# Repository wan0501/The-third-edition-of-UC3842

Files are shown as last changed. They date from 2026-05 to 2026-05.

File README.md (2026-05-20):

# UC3842 第三版 — 85VAC~265VAC 输入 / 24VDC 3A 输出反激开关电源
本项目是一个基于 **UC3842**  PWM 控制芯片的**反激（Flyback）式开关电源**完整设计，提供 **85 VAC ~ 265 VAC 宽范围交流输入**、**24 VDC / 3 A（72 W）稳压直流输出**。
这是该电源的**第三版**设计，在之前版本基础上对电路参数、变压器设计和布局进行了全面优化。

---

## 目录

- [项目概述](#项目概述)
- [技术规格](#技术规格)
- [文件说明](#文件说明)
- [电路架构](#电路架构)
- [关键设计要点](#关键设计要点)
- [设计工具](#设计工具)
- [使用说明](#使用说明)
- [版本历史](#版本历史)
- [许可证](#许可证)

---

## 项目概述

本项目以 UC3842 电流模式 PWM 控制器为核心，设计一款适用于工业控制、仪器仪表、辅助供电等场景的隔离型反激开关电源。第三版重点对以下方面进行了改进：

- **优化变压器**：重新计算电感量、匝比和磁芯选择，提高效率
- **改进 EMI 滤波**：增强输入滤波和共模抑制
- **完善保护功能**：过流保护（OCP）、过压保护（OVP）、欠压锁定（UVLO）
- **优化布局**：减少噪声耦合，改善热管理

### 应用场景

- 工业控制系统辅助电源
- 仪器仪表供电
- 白色家电控制板电源
- 通用 AC-DC 适配器 / 基板电源

---

## 技术规格

| 参数 | 最小值 | 典型值 | 最大值 | 单位 |
|---|---|---|---|---|
| **输入电压 (AC)** | 85 | 220 | 265 | VAC |
| **输入频率** | 47 | 50/60 | 63 | Hz |
| **输出电压** | — | 24.0 | — | VDC |
| **输出电流** | 0 | 3.0 | — | A |
| **输出功率** | — | 72 | — | W |
| **开关频率** | — | ~65 | — | kHz |
| **效率** | >80 | ~85 | — | % |
| **纹波噪声** | — | <100 | — | mVpp |
| **负载调整率** | — | ±1 | — | % |
| **电压调整率** | — | ±0.5 | — | % |
| **隔离耐压** | 3000 | — | — | VAC |

---

## 文件说明

| 文件 | 说明 |
|---|---|
| `UC3842第三版.SchDoc` | **Altium Designer 原理图源文件**，包含完整的电路设计和元件参数 |
| `UC3842第三版.pdf` | **原理图 PDF 导出文件**，方便直接查看和打印 |
| `85AC~265VAC-DC24V3A.xlsx` | **变压器设计计算表格**，包含电感量、匝数、磁芯选型、损耗等详细计算 |
| `22LC串联谐振频率计算工具.xlsx` | **LC 串联谐振频率计算工具**，用于辅助设计 RCD 吸收回路 / 谐振网络 |

---

## 电路架构

### 系统框图

```
AC输入 (85~265V) → EMI滤波 → 桥式整流 → 输入滤波电容 → 反激变压器 → 输出整流滤波 → 24VDC 输出
                           ↑                        ↓
                       PWM 驱动 (UC3842) ←─── 反馈环路 (TL431 + 光耦)
```

### 主要功能模块

#### 1. 输入级
- **保险丝**：输入过流保护
- **NTC 热敏电阻**：抑制启动浪涌电流
- **共模扼流圈 + X 电容**：EMI 共模滤波
- **桥式整流器**：全波整流
- **大容量电解电容**：整流滤波，提供平滑直流母线

#### 2. 控制级 — UC3842
- **启动电阻**：上电启动，启动后由辅助绕组供电
- **RC 振荡**：设定开关频率（约 65 kHz）
- **电流检测电阻**：逐周期峰值电流限制
- **软启动**：缓启动电路，避免启动过冲

#### 3. 功率级 — 反激变换
- **MOSFET 开关管**：高压功率管
- **RCD 吸收回路**：抑制漏感尖峰电压
- **反激变压器**：储能、隔离、电压变换

#### 4. 输出级
- **肖特基整流二极管**：高效输出整流
- **LC 滤波**：降低输出纹波
- **假负载电阻**：保障空载稳定性

#### 5. 反馈环路
- **TL431 精密基准**：输出采样与误差放大
- **PC817 光耦**：隔离反馈，提供初级侧 PWM 控制

---

## 关键设计要点

### 变压器设计

变压器是反激电源的核心。计算表格 `85AC~265VAC-DC24V3A.xlsx` 中包含了详细的设计过程：

- **磁芯选型**：根据功率等级选择合适磁芯（如 EE / PQ / RM 系列）
- **匝比计算**：根据输入电压范围和输出电压确定最优匝比
- **电感量**：在 CCM / DCM 模式下优化电感量，平衡峰值电流和磁芯损耗
- **气隙计算**：防止磁饱和
- **绕组结构**：优化初级、次级、辅助绕组的排布，降低漏感
- **铜损 / 铁损**：校核温升

> **注意**：变压器参数已根据第三版优化调整，请勿直接套用前两版参数。

### RCD 吸收回路

- **LC 串联谐振频率计算工具**（`22LC串联谐振频率计算工具.xlsx`）辅助选择吸收电容和电阻
- 目标：将漏感尖峰电压控制在 MOSFET 耐压范围内（通常降额 80%~85%）
- 平衡：吸收效果 vs 损耗

### 反馈补偿

- Type II 补偿网络（TL431 + RC 网络）
- 穿越频率设为开关频率的 1/5 ~ 1/10
- 保证足够的相位裕度（>45°）

### 布局要点（建议）

- **功率回路**：最小化高频电流环路面积
- **控制地 / 功率地**：单点接地 / 星形接地
- **隔离间距**：初级 - 次级间确保安全爬电距离
- **散热**：MOSFET 和整流二极管留足铜皮散热

---

## 设计工具

| 工具 | 用途 |
|---|---|
| Excel 计算表格 | 变压器参数计算、LC 谐振频率计算 |
| UC3842 Datasheet (TI / OnSemi / ST) | 芯片参考设计 |

---

## 使用说明

### 查看原理图

1. **方式一（推荐）**：使用 Altium Designer 打开 `UC3842第三版.SchDoc`
2. **方式二**：直接打开 `UC3842第三版.pdf` 查看原理图 PDF

### 使用设计计算表格

- `85AC~265VAC-DC24V3A.xlsx`：修改黄色的输入参数单元格，自动计算变压器参数
- `22LC串联谐振频率计算工具.xlsx`：输入电感和电容值，自动计算谐振频率

### 注意事项

- **高压危险！** 调试时建议使用隔离变压器
- 初次上电建议串联调压器 + 灯泡限流
- 修改变压器参数后请重新验证磁通摆幅（ΔB），防止磁饱和

---

## 版本历史

| 版本 | 日期 | 说明 |
|---|---|---|
| V1.0 | — | 初始设计 |
| V2.0 | — | 优化反馈环路和 EMI |
| **V3.0** | **当前** | **全面优化变压器、吸收回路和布局** |

---

## 许可证

本项目基于 MIT 许可证开源 — 详见 [LICENSE](LICENSE) 文件。

---

## 免责声明

本项目为开源硬件设计参考，**不构成产品级设计保证**。使用者应自行验证电路参数是否满足自身应用需求。因使用本设计造成的任何损失，作者不承担责任。

---

**作者**: [wan0501](https://github.com/wan0501)

**如果这个项目对你有帮助，欢迎 Star ⭐ 和 Fork！**

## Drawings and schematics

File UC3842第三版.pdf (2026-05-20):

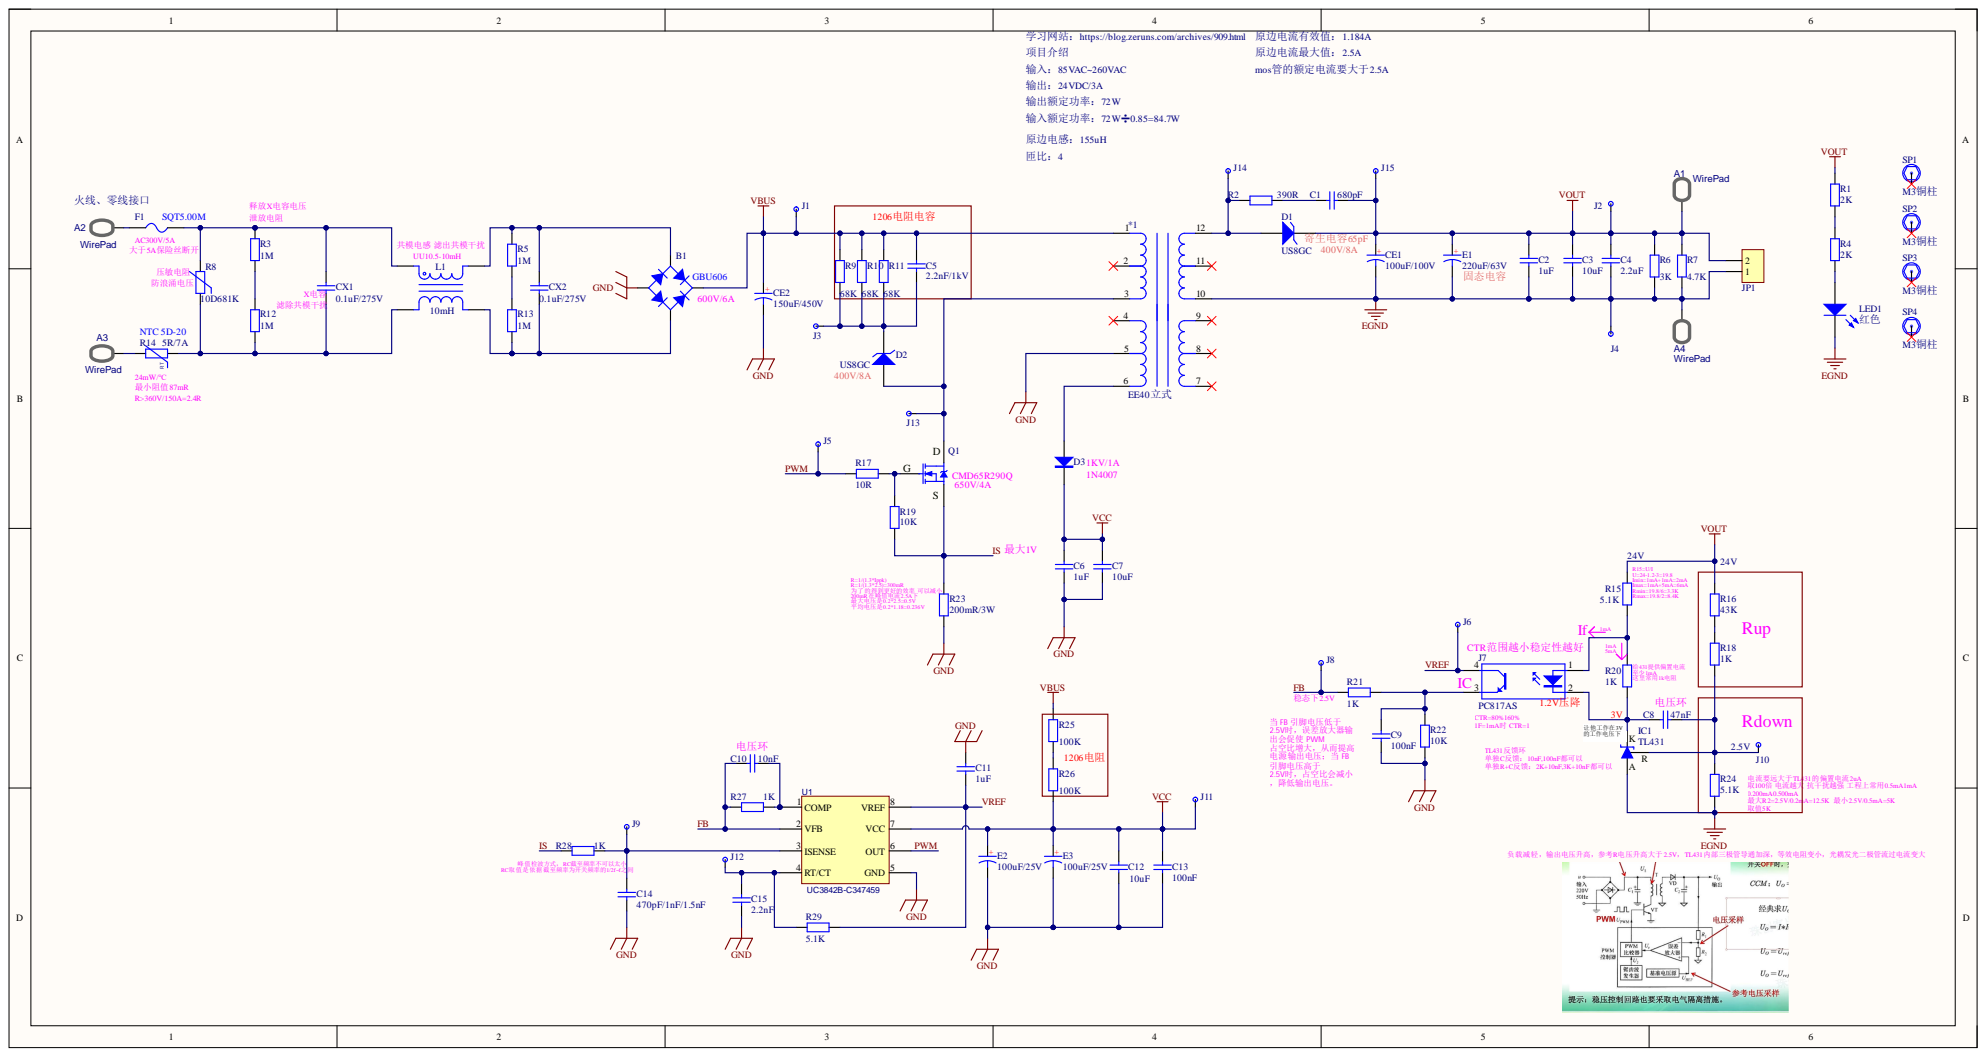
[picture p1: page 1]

给431提供偏置电流 至少1mA 这里常用1k电阻 R15=U/I U=24-1.2-3=19.8 Imin=1mA+1mA=2mA Imax=1mA+5mA=6mA Rmin=19.8/6=3.3K Rmax=19.8/2=8.4K

出会促使 PWM
占空比增大，从而提高 电源输出电压；当 FB

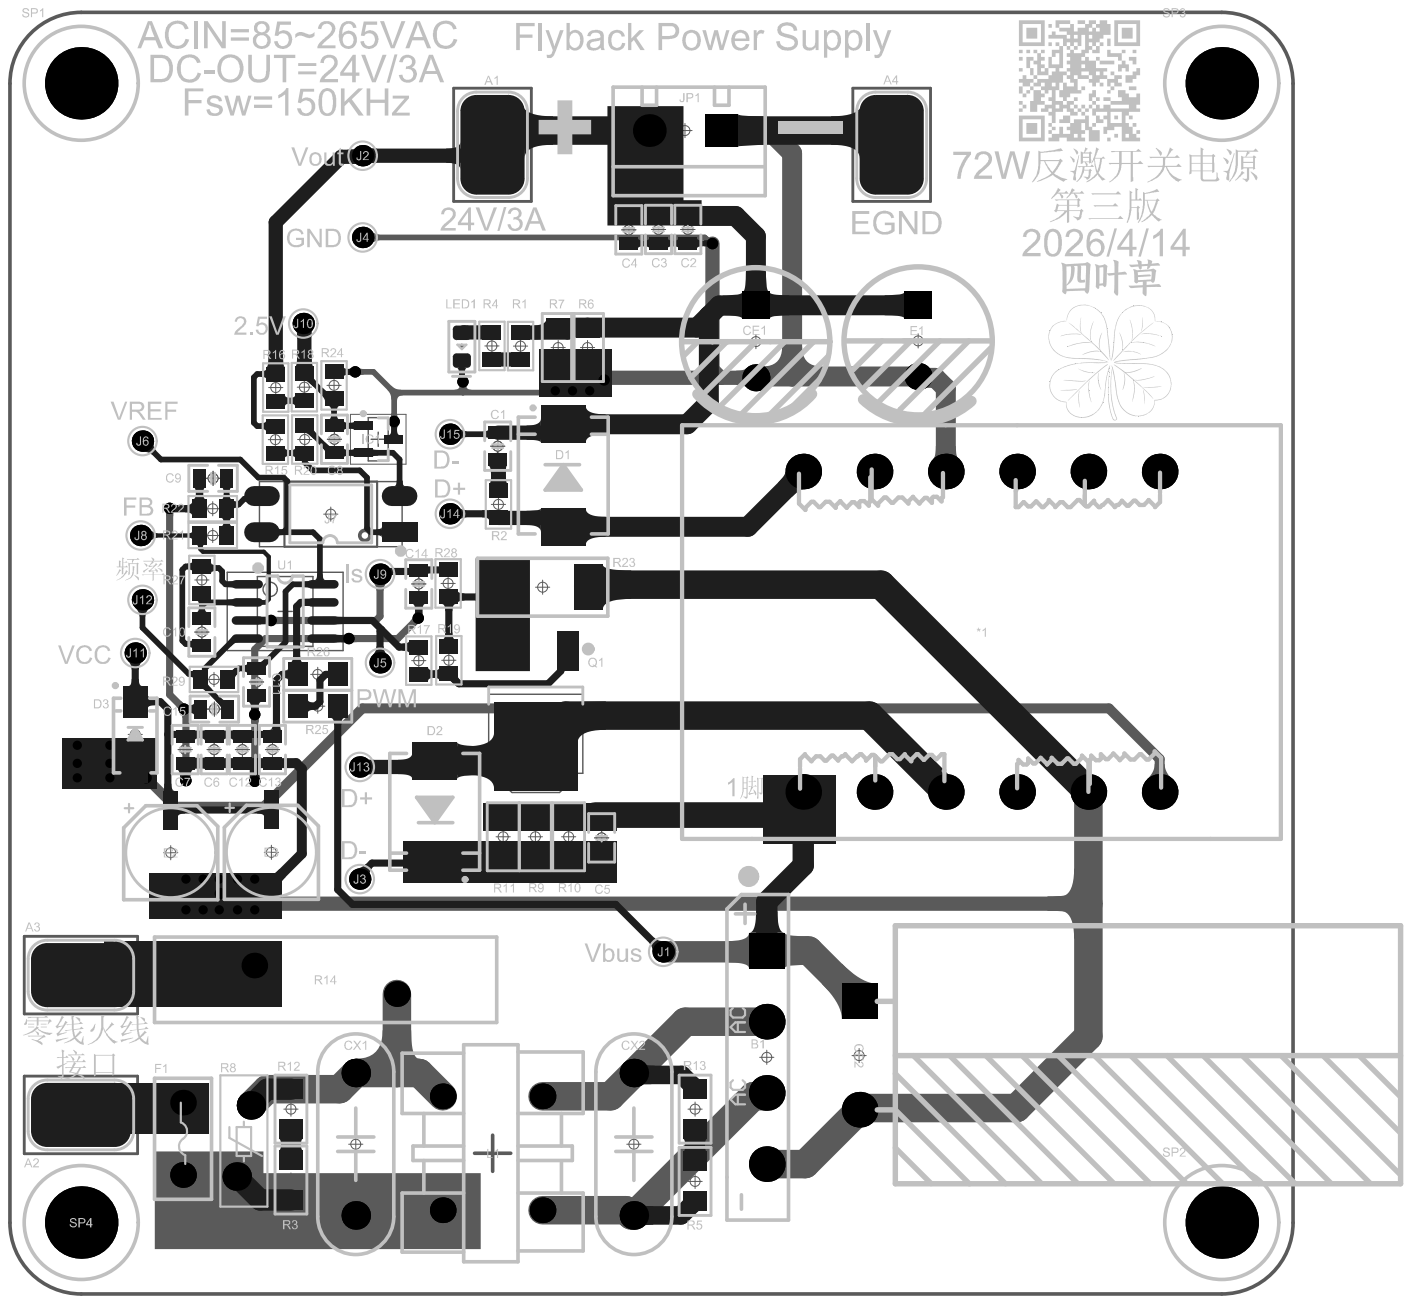
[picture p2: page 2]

Comment | Description | Designator | Footprint | LibRef | Quantity
EE40立式 | | *1 | EE40立式 | EE40立式 | 1
GBU606 | 1KV/10A整流桥 | B1 | GBU | GBU | 1
680pF | 贴片电容/MLCC电容 | C1 | C0805_L | C | 1
1uF | 贴片电容/MLCC电容 | C2, C6, C11 | C0805_L | C | 3
10uF | 贴片电容/MLCC电容 | C3, C7, C12 | C0805_L | C | 3
2.2uF | 贴片电容/MLCC电容 | C4 | C0805_L | C | 1
2.2nF/1kV | 贴片电容/MLCC电容 | C5 | C0805_L | C | 1
47nF | 贴片电容/MLCC电容 | C8 | C0805_L | C | 1
100nF | 贴片电容/MLCC电容 | C9, C13 | C0805_L | C | 2
10nF | 贴片电容/MLCC电容 | C10 | C0805_L | C | 1
470pF/1nF/1.5nF | 贴片电容/MLCC电容 | C14 | C0805_L | C | 1
2.2nF | 贴片电容/MLCC电容 | C15 | C0805_L | C | 1
100uF/100V | 直插电解电容 | CE1 | CE-5.0*10*16 | CE | 1
150uF/450V | 直插电解电容 | CE2 | CE-7.5*18*35.5-H -BK | CE | 1
0.1uF/275V | 安规X电容 | CX1, CX2 | CX 10*13*11 | CX | 2
US8GC | 5000W 24V TVS二极 管 | D1, D2 | SMC | 5.0SMDJ24A | 2
1N4007 | 整流二极管 | D3 | SMA | 1N4007 | 1
220uF/63V | 直插固态电容 | E1 | CT 5.0*10*13 - R | CS | 1
100uF/25V | 贴片电解电容 | E2, E3 | CE D(6.3*5.4) | CE_SMD | 2
SQT5.00M | 方形保险丝 | F1 | FUSE-8.5x4.0-392Series | FUSE-8.5*4.0*8.0 | 1
TL431 | 贴片可调基准稳压芯 片 | IC1 | SOT23-3N | TL431_SMD | 1
CHECK | 测试点 | J1, J2, J3, J4, J5, J6, J8, J9, J10, J11, J12, J13, J14, J15 | CHECK-A | CHECK | 14
PC817AS | 1路开关光耦 | J7 | SOP4-W2.54_M | TLP521-1 | 1
HDR-1X2 | 2P接插件 | JP1 | KF301-5.0-2P | Header 2 | 1
10mH | UU型共模电感 | L1 | UU9.8 | L-UU | 1
红色 | 贴片LED | LED1 | LED0805_G | LED | 1
CMD65R290Q | N沟道 100V/40A | Q1 | TO252 | P40NF10L | 1
2K | 贴片电阻 | R1, R4 | R0805_L | R | 2
390R | 贴片电阻 | R2 | R0805_L | R | 1
1M | 贴片电阻 | R3, R5, R12, R13 | R1206_L | R | 4
3K | 贴片电阻 | R6 | R1206_L | R | 1
4.7K | 贴片电阻 | R7 | R1206_L | R | 1
10D681K | 压敏电阻 | R8 | VDR 9D-4.5 | R_VSR | 1
68K | 贴片电阻 | R9, R10, R11 | R1206_L | R | 3
5R/7A | 热敏电阻 | R14 | NTC-5D-20 | RT | 1
5.1K | 贴片电阻 | R15, R24, R29 | R0805_L | R | 3
43K | 贴片电阻 | R16 | R0805_L | R | 1
10R | 贴片电阻 | R17 | R0805_L | R | 1
1K | 贴片电阻 | R18, R20, R21, R27, R28 | R0805_L | R | 5
10K | 贴片电阻 | R19, R22 | R0805_L | R | 2
200mR/3W | 贴片电阻 | R23 | R2512_M | R | 1
100K | 贴片电阻 | R25, R26 | R1206_L | R | 2
M3铜柱 | 铜柱 | SP1, SP2, SP3, SP4 | M3x9_L | 铜柱小焊盘 | 4
UC3842B-C347459 | 开关电源芯片 | U1 | SOIC-8_150mil | UC3842 | 1
